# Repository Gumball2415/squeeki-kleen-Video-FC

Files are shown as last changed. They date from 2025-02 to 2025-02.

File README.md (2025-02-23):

# squeeki-kleen-Video-FC

An open source hardware external composite video bypass preamplifier modboard
for the Famicom/NES

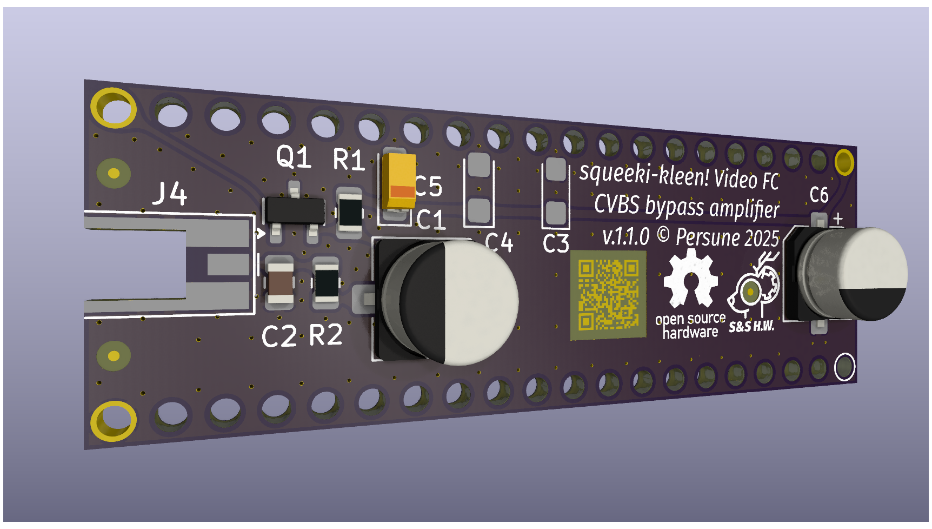
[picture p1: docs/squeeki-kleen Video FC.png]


## About

I made a compact daughterboard composite video output based on the
[composite amplifier circuit from the AV Famicom](https://www.nesdev.org/wiki/PPU_pinout#Composite_Video_Output).
This is designed to make AV modding RF-only consoles such as the RF Famicom and the Toploading NES-101 compact and simple.

## How to install

TODO: image demonstrations.

1. If your board does not have tented vias, cover the area underneath the PPU with insulating tape. Be sure to also cover underneath the MMCX connector footprint to avoid shorts.
2. To reduce stray inductive connections, isolate pin 21 of the PPU by cutting any traces connecting to it as close to the through-hole pad as much as possible.
3. If needed, add additional bypass capacitors in the empty C3 and C4 footprints.

## PCB specifications

Note that this project is optimized for JLCPCB manufacturing.

- 2 layers
- 50.80 x 17.78 mm
- 0.8 mm thickness (or 1.60 mm if you plan to attach the MMCX connector)
- Any surface finish
- Any soldermask/silkscreen color
- Tented vias
	- alternatively, cover area under board with kapton/insulative tape

## License

This is licensed under the [TAPR Open Hardware Licence](https://tapr.org/the-tapr-open-hardware-license/). Copyright Persune 2025.

## Credits

Special thanks to:
- The NESDev community for advice and help
- lidnariq for advice
- Finny (grievre/arreffem) for inspiration
- j4m13c0 for testing the board (and notifying me of Q1 pinout error!)

## Support

If you enjoy this project or find it helpful, please support me using the links below!

- 
- [Patreon](https://patreon.com/persune)

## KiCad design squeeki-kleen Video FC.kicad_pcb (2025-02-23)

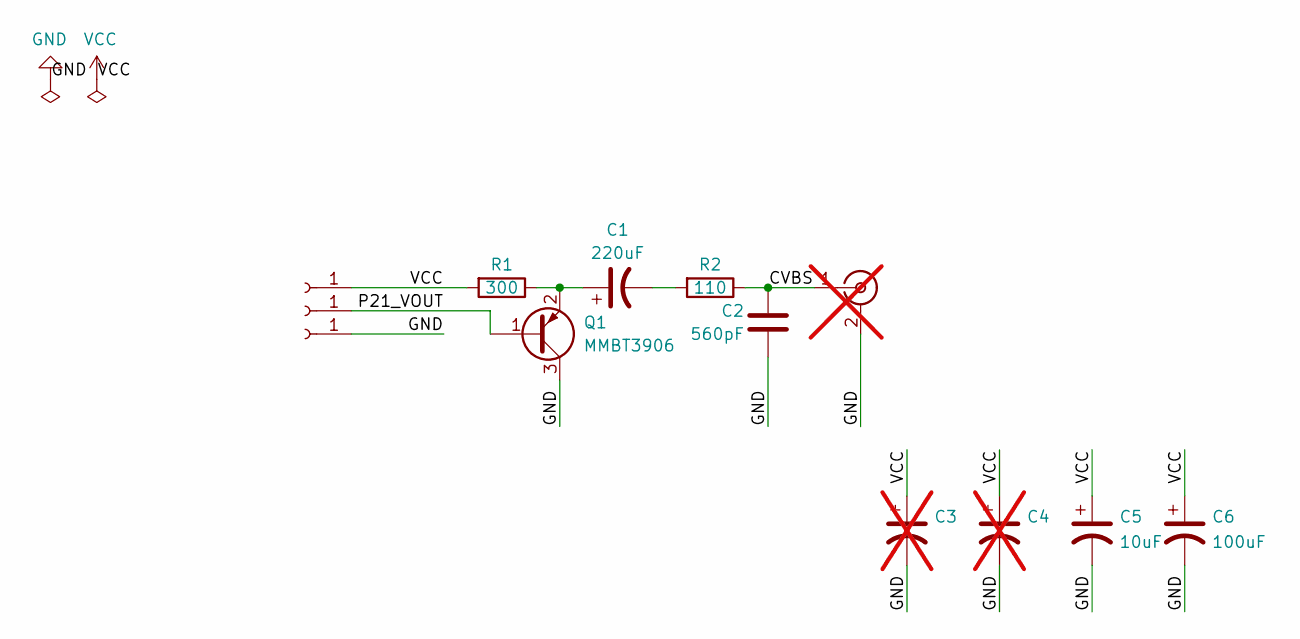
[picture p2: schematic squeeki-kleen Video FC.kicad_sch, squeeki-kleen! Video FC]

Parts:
C1: 220uF; CP_Elec_6.3x5.4; LCSC C72494
C2: 560pF; C_0805_2012Metric; LCSC C527188
C3, C4: CP_EIA-3216-18_Kemet-A; LCSC C1508940; not fitted
C5: 10uF; CP_EIA-3216-18_Kemet-A; LCSC C1508940
C6: 100uF; CP_Elec_6.3x4.5; LCSC C5374788
J1: VCC; THT_Hole
J2: VOUT; THT_Hole
J3: GND; THT_Hole
J4: Conn_Coaxial; MMCX_Molex_73415-0961_Horizontal_0.8mm-PCB; not fitted
Q1: MMBT3906; SOT-23; LCSC C2891809
R1: 300; R_0805_2012Metric; LCSC C17617
R2: 110; R_0805_2012Metric; LCSC C229072

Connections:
/CVBS: C2.1, J4.1 (In), R2.1
/P21_VOUT: J2.1, Q1.1 (B)
GND: C2.2, C3.2, C4.2, C5.2, C6.2, J3.1, J4.2 (Ext), Q1.3 (C)
unnamed: C1.2, R2.2
unnamed: C1.1, Q1.2 (E), R1.1
VCC: C3.1, C4.1, C5.1, C6.1, J1.1, R1.2

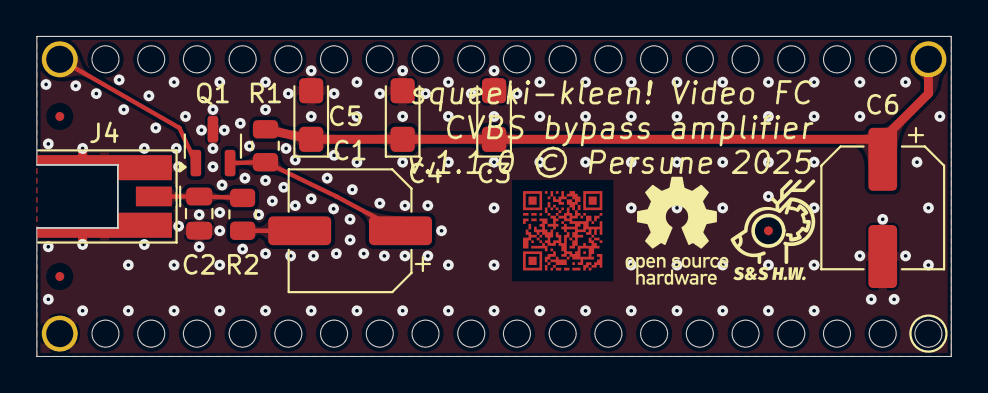
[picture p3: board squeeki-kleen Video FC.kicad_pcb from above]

Board: 2 copper layers, 50.8 x 17.8 mm, 16 parts (0 on the bottom side), 6 nets.

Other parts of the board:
svg2mod: G***; qr
svg2mod#2: G***; maustech icon fiducial 0-50mm 1-50mm
svg2mod#3: G***; oshw-logo 6x6mm

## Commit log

2022-12-21 Initial board
    [squeeki-kleen Video FC.kicad_pcb, squeeki-kleen Video FC.kicad_sch, squeeki-kleen Video FC.sch]
2023-03-06 Big changes
    - Fix MMBT3906 pinout
    - Use NPTH instead of edge cut circles
    - Update silkscreen art
    - Add 100uF electrolytic capacitor for power
    [squeeki-kleen Video FC-rounded.kicad_pcb, squeeki-kleen Video FC.kicad_sch]
2023-03-06 Update revision date
    [squeeki-kleen Video FC.kicad_pcb, squeeki-kleen Video FC.kicad_sch]
2023-03-06 Update PCB image
2023-04-05 Update silkscreen art to add QR code
    [squeeki-kleen Video FC-rounded.kicad_pcb, squeeki-kleen Video FC.kicad_pcb]
2023-04-05 Implement four-module quiet zone in QR code
    [squeeki-kleen Video FC-rounded.kicad_pcb, squeeki-kleen Video FC.kicad_pcb]
2023-04-07 Update schematic to Kicad 7.0
    [squeeki-kleen Video FC.kicad_sch]
2023-04-07 Add version number to PCB
    [squeeki-kleen Video FC-rounded.kicad_pcb, squeeki-kleen Video FC.kicad_pcb, squeeki-kleen Video FC.kicad_sch]
2025-02-23 Compact component placement, add teardrops
    [squeeki-kleen Video FC-rounded.kicad_pcb, squeeki-kleen Video FC.kicad_pcb, squeeki-kleen Video FC.kicad_sch]
2025-02-23 Widen holes, add extra empty capacitor footprints
    [squeeki-kleen Video FC-rounded.kicad_pcb, squeeki-kleen Video FC.kicad_pcb, squeeki-kleen Video FC.kicad_sch]

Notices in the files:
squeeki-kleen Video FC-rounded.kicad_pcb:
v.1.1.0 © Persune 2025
